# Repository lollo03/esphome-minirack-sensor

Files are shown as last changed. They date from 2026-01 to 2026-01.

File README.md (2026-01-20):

# Air Quality & Presence Station (ESPHome)

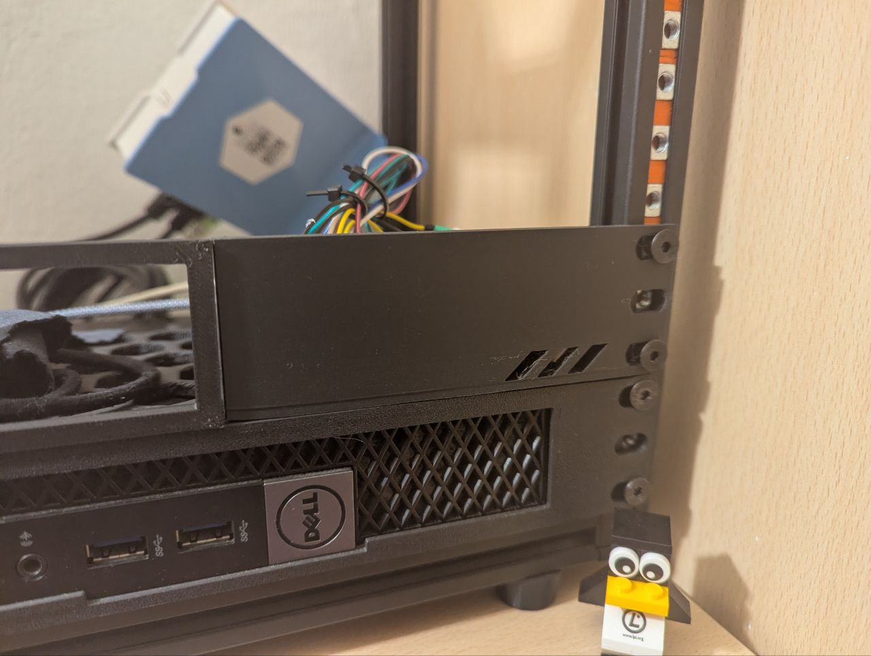
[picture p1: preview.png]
My Minirack Sensor


A standalone, multi-sensor station built on the **ESP8266 NodeMCU V2**. It monitors indoor air quality (PM2.5, CO2, TVOC), temperature, humidity, and detects human presence using mmWave radar.

The device runs a local **Web Server** (accessible via browser) and integrates seamlessly with **Home Assistant**.

---

## 🛠️ Hardware Required

| Component | Quantity | Voltage | Notes |
| --- | --- | --- | --- |
| **NodeMCU V2 (ESP-12E)** | 1 | 5V (USB) | Main Controller |
| **PM1006** | 1 | **5V** | LED Particle Sensor |
| **AHT21 + ENS160** | 1 | **3.3V** | Combo Module (I2C) |
| **HLK-LD2410C** | 1 | **5V** | mmWave Radar |

---

🖨️ 3D Enclosure / Case

A custom 3D printed case has been designed for this project to fit the NodeMCU and sensors ("Minirack" style). You can view, measure, and download the STL/STEP files directly from Onshape.

[View 3D designs](https://cad.onshape.com/documents/e66a7972bee8e0914a29a0f6/w/74442f743c7efd9fbcd983ab/e/899fb40ebec1d5741c28e923)

[View on Printables](https://www.printables.com/model/1559845-esphome-multisensor-station-minirack-nodemcu-v2)

---

## ⚙️ Pre-Installation (Crucial!)

Before assembling, you must change the baud rate of the **LD2410 Radar**:

1. Power the LD2410 (5V & GND).
2. Download the **HLKRadarTool** app on your smartphone.
3. Connect to the sensor via Bluetooth.
4. Change Baud Rate from `256000` to **`38400`**.
5. Save and Restart the sensor.

*If you do not do this, the radar will not work with this configuration.*

---

## 📥 Installation

### 1. Secrets File

Create a file named `secrets.yaml` in your ESPHome config folder:

```yaml
wifi_ssid: "YOUR_WIFI_NAME"
wifi_password: "YOUR_WIFI_PASSWORD"
```

### 2. Flash Firmware

1. Connect the NodeMCU to your PC via USB.
2. Run `esphome run air-station.yaml`.
3. Once flashed, the device will connect to WiFi.
4. **Note:** You can leave the USB connected to view logs; the UART conflicts are resolved in this configuration.

---

## 📊 How to Use

### Web Interface (Standalone)

1. Find the device IP address (check your router or the USB logs).
2. Open a browser and type: `http://<DEVICE_IP>`.
3. You will see real-time values for all sensors.

---

## 📝 License

This project is open source. Use it, modify it, breathe clean air!

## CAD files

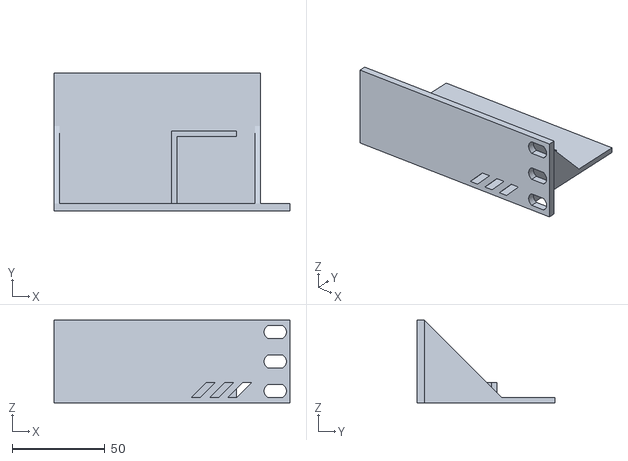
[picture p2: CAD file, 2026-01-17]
sensor-enclosure.stl
127.0 x 74.0 x 44.5

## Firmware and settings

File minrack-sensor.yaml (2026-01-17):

esphome:
  name: stazione-aria-completa
  friendly_name: "Minirack Sensor"

esp8266:
  board: nodemcuv2

logger:
  level: DEBUG
  baud_rate: 115200

web_server:
  port: 80

api:

ota:
  platform: esphome

wifi:
  ssid: !secret wifi_ssid
  password: !secret wifi_password
  ap:
    ssid: "Air-Setup"
    password: "setup_password"

i2c:
  sda: D1
  scl: D2
  scan: true
  id: bus_a

uart:
  - id: uart_pm1006
    tx_pin: D6
    rx_pin: D5
    baud_rate: 9600

  - id: uart_ld2410
    tx_pin: D0
    rx_pin: D7
    baud_rate: 38400
    parity: NONE
    stop_bits: 1

ld2410:
  uart_id: uart_ld2410

sensor:
  - platform: aht10
    variant: AHT20
    i2c_id: bus_a
    temperature:
      name: "Temperature"
      id: temp_aht
      filters:
        - offset: -4.0 # adjustment for calibration
    humidity:
      name: "Humidity"
      id: hum_aht
    update_interval: 60s

  - platform: ens160_i2c
    i2c_id: bus_a
    address: 0x53
    eco2:
      name: "Equivalent CO2"
    tvoc:
      name: "TVOC"
    aqi:
      name: "Air Quality Index"
    compensation:
      temperature: temp_aht
      humidity: hum_aht
    update_interval: 60s

  - platform: pm1006
    uart_id: uart_pm1006
    pm_2_5:
      name: "PM2.5"
      filters:
        - sliding_window_moving_average:
            window_size: 5
            send_every: 1
    update_interval: 30s

  - platform: ld2410
    moving_distance:
      name: "Moving Distance"
    still_distance:
      name: "Still Distance"

binary_sensor:
  - platform: ld2410
    has_target:
      name: "Presence Detected"
    has_moving_target:
      name: "Motion Detected"
    has_still_target:
      name: "Still Target Detected"

switch:
  - platform: ld2410
    bluetooth:
      name: "Radar Bluetooth"
